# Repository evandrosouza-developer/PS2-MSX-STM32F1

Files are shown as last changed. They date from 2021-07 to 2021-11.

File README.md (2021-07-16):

# STM32: PS/2 to USB Converter

This code facilitates a STM32 chip to convert between PS/2 and MSX computer. It is meant to connect a keyboard, which only provides a PS/2 connector, to a MSX (or any one that have a up to 15 active columns and reads zeroes througth 8 bits - up to 15 x 8 matrix) computer.
This code powers and has been tested on the following Windows keyboards with brazilian 275 layout:
- Compaq RT235BTWBR;
- Clone KE11090749;
- Clone #09100.

The original code was originally developed based on:
- Cherry G80-3000LSMDE;

## Dependencies

- `arm-none-eabi-gcc`
- `arm-none-eabi-gdb`
- `arm-none-eabi-binutils`
- `arm-none-eabi-newlib`
- `stlink`
- `openocd (if you wnat to debug)`
- `mpfr`

## Preparations

After cloning the repository you need to make the following preparations:

```
git submodule init
git submodule update
cd libopencm3
make
cd ..
make
```

## Hardware and Setup

You will obviously need a STM32F103C8T6 chip. I have used a chinese blue pill. The software was made thinking in use of compatible processors, like GD32 for example. The software was made considering 8.000Mhz oscillator crystal, to clock the STM32F103C8T6 microcontroller chip at 72MHz. The connections are:

1) PS/2 Keyboard:
- Clock Pin PA12 - Connect to PS/2 mini-din 45322 pin 5 throught R16;
- Data Pin PA9 - Connect to PS/2 mini-din pin 1 throught R18;
- +5V PS/2 power - Connect collector of Q2 to mini-din pin 4;
- GND - Connect GNDD (Digital Ground) to mini-din pin 3.

2) MSX computer:
Obs.: You have to access PPI Ports B0 to B7 (Lines X0 to X7), Port C0 to C3 (Y0 to Y3), Port C6 (Caps Lock, pin 11 of DIP package), and for Russian and Japanese Computers (Cyrillic and Kana alphabets), you have to get access to YM2149 IOB7, pin 6 of DIP package.
- Y3 - Connect to MSX PPI 8255 Signal PC3;
- Y2 - Connect to MSX PPI 8255 Signal PC2;
- Y1 - Connect to MSX PPI 8255 Signal PC1;
- Y0 - Connect to MSX PPI 8255 Signal PC0;
- X7 - Connect to MSX PPI 8255 Signal PB7 (Hotbit HB-8000 CI-15 Pin 25);
- X6 - Connect to MSX PPI 8255 Signal PB6 (Hotbit HB-8000 CI-15 Pin 24);
- X5 - Connect to MSX PPI 8255 Signal PB5 (Hotbit HB-8000 CI-15 Pin 23);
- X4 - Connect to MSX PPI 8255 Signal PB4 (Hotbit HB-8000 CI-15 Pin 22);
- X3 - Connect to MSX PPI 8255 Signal PB3 (Hotbit HB-8000 CI-15 Pin 21);
- X2 - Connect to MSX PPI 8255 Signal PB2 (Hotbit HB-8000 CI-15 Pin 20);
- X1 - Connect to MSX PPI 8255 Signal PB1 (Hotbit HB-8000 CI-15 Pin 19);
- X0 - Connect to MSX PPI 8255 Signal PB0 (Hotbit HB-8000 CI-15 Pin 18);
- Caps LED - Connect to MSX PPI 8255 Signal PC6 (Hotbit HB-8000 CI-15 Pin 11 / Expert XP-800 CI-4);
- Kana LED - Connect to MSX YM2149 IOB7, pin 6 of DIP package. If the MSX doesn't have this, you can leave it open, as it already has an internal pull-up connection.

3) Serial connection: Needed only to update internal PS/2 to MSX key mapping Database. To create this Intel Hex file, better to use the Macro based Excel file, so you have to trust and enable macro excecution in excel app.
The structure of the Database is:
	The  three first columns of each line are the mapped scan codes;
	The 4th column is The Control Byte, detailed bellow:
	CONTROL BYTE:
		High nibble is Reserved;
		(bit 3) Combined Shift;
		(bit 2) Reserved-Not used;
		(bits 1-0) Modifyer Type:
		.0 - Default mapping
		.1 - NumLock Status+Shift changes
		.2 - PS/2 Shift
		.3 - Reserved-Not used
	
	This table has 3 modifyers: Up two MSX keys are considered to each mapping behavior modifying:
	
	5th and 6th columns have the mapping ".0 - Default mapping";
	7th e 8th columns have the mapping ".1 - NumLock Status+Shift changes";
	9th and 10th columns have the mapping ".2 - PS/2 Shift", where I need to
	release the sinalized Shift in PS/2 to the MSX and put the coded key, and so,
	release them, reapplying the Shift key, deppending on the initial state;

	Each column has a MSX coded key, with the sollwing structure:
	(Bit 7:4) MSX Y PPI 8255 PC3:0 is send to an OC outputs BCD decoder, for example:
					 In the case of Hotbit HB8000, the keyboard scan is done as a 9 columns scan, CI-16 7445N 08 to 00;
					 If equals to 1111 (Y=15), there is no MSX key mapped.
	(Bit 3)	 		 0: keypress
					 1: key release;
	(Bit 2:0) MSX X, ie, which bit will carry the key, to be read by PPI 8255 PB7:0.

Use a ST-Link v2 Programmer (or similar) to flash the program using `make flash` onto the STM32.

# PS2-MSX-STM32F1
# PS2-MSX-STM32F1

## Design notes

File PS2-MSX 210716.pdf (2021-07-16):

PPT模板下载：www.1ppt.com/moban/ 行业PPT模板：www.1ppt.com/hangye/ 节日PPT模板：www.1ppt.com/jieri/ PPT素材下载：www.1ppt.com/sucai/ PPT背景图片：www.1ppt.com/beijing/ PPT图表下载：www.1ppt.com/tubiao/
优秀PPT下载：www.1ppt.com/xiazai/ | PPT教程： www.1ppt.com/powerpoint/
Word教程： www.1ppt.com/word/ | Excel教程：www.1ppt.com/excel/
资料下载：www.1ppt.com/ziliao/
PPT课件下载：www.1ppt.com/kejian/
范文下载：www.1ppt.com/fanwen/

# PS/2 Keyboard for MSX And Legacy computers

## Evandro Souza <evandro.r.souza@gmail.com

# Based on ARM Cortex M3 Blue Pill STM32F103C8T6

# Introdução

O principal objetivo foi aprender a usar o Ecossistema de Desenvolvimento aberto (free) ARM Core M3

Para tal, escolhi uma aplicação de missão crítica, implementando facilidades de configuração normalmente não observadas nas várias soluções inteligentes já implementadas, como, por exemplo, permitir a atualização da tabela de conversão sem a necessidade e de recompilar o código.

Solução simples e de baixo custo

# Índice

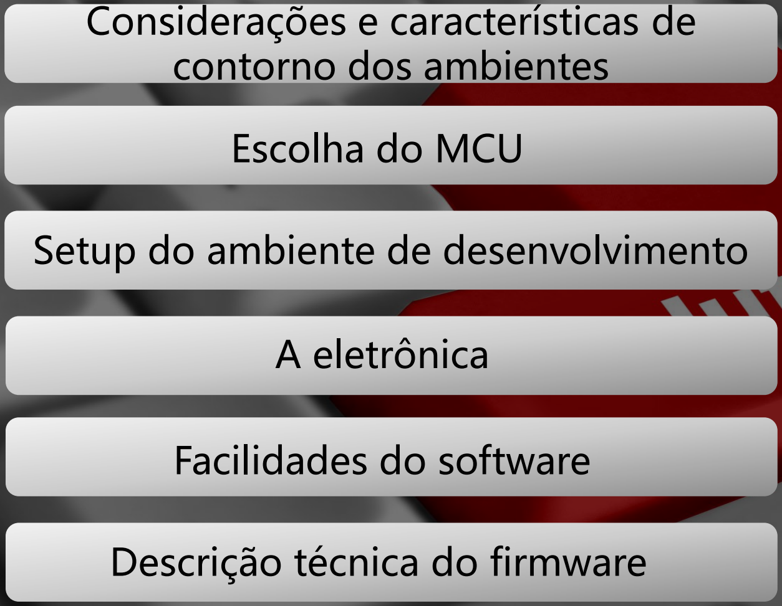
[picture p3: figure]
Considerações e características de contorno dos ambientes; Escolha do MCU; Setup do ambiente de desenvolvimento; A eletrônica; Facilidades do software; Descrição técnica do firmware

# Assunto do momento

# Considerações e características de

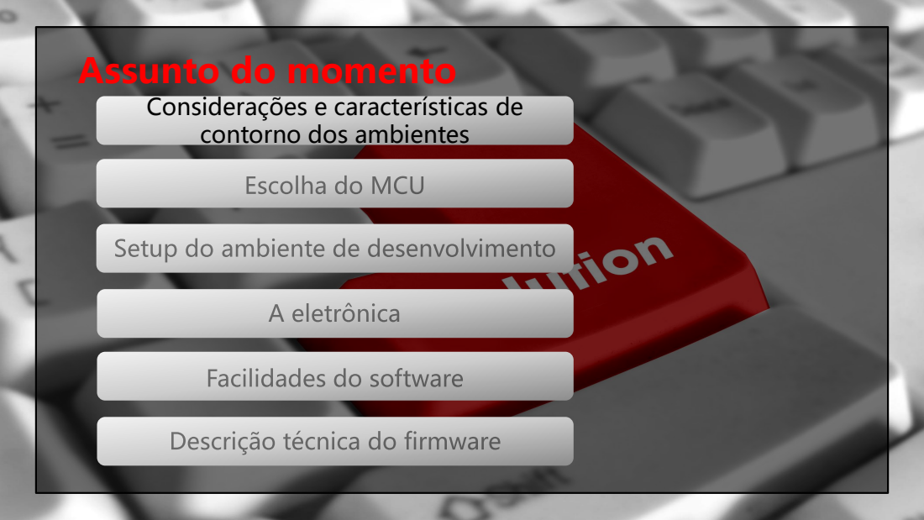
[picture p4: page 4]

contorno dos ambientes

# Esquemas exemplo de MSX

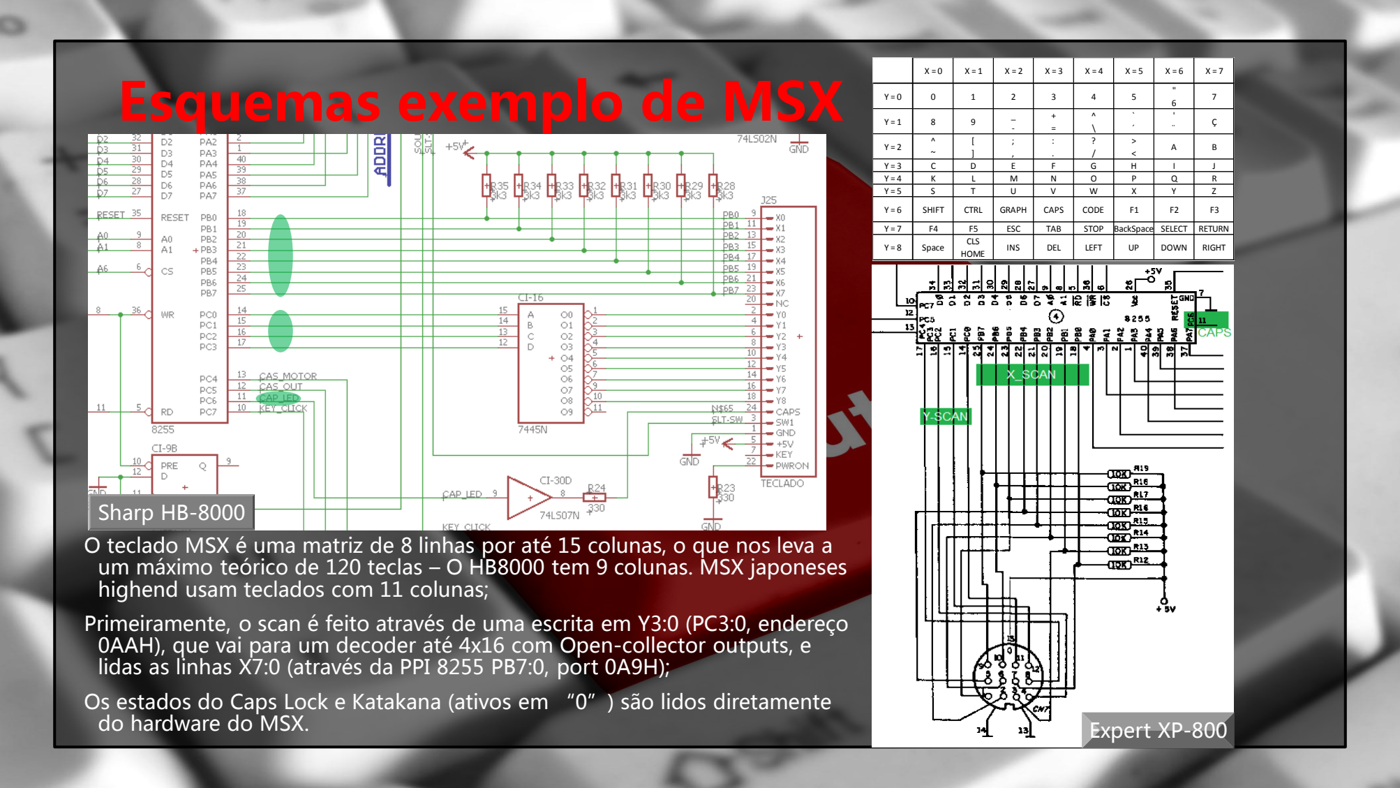
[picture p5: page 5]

O teclado MSX é uma matriz de 8 linhas por até 15 colunas, o que nos leva a um máximo teórico de 120 teclas – O HB8000 tem 9 colunas. MSX japoneses highend usam teclados com 11 colunas;
Primeiramente, o scan é feito através de uma escrita em Y3:0 (PC3:0, endereço 0AAH), que vai para um decoder até 4x16 com Open-collector outputs, e lidas as linhas X7:0 (através da PPI 8255 PB7:0, port 0A9H);
Os estados do Caps Lock e Katakana (ativos em “0”) são lidos diretamente do hardware do MSX.

Sharp HB-8000

Expert XP-800

| X = 0 | X = 1 | X = 2 | X = 3 | X = 4 | X = 5 | X = 6 | X = 7
Y = 0 | 0 | 1 | 2 | 3 | 4 | 5 | " 6 | 7
Y = 1 | 8 | 9 | _ - | + = | ^ \ | ` ´ | ' ¨ | Ç
Y = 2 | ^ ~ | [ ] | ; , | : . | ? / | > < | A | B
Y = 3 | C | D | E | F | G | H | I | J
Y = 4 | K | L | M | N | O | P | Q | R
Y = 5 | S | T | U | V | W | X | Y | Z
Y = 6 | SHIFT | CTRL | GRAPH | CAPS | CODE | F1 | F2 | F3
Y = 7 | F4 | F5 | ESC | TAB | STOP | BackSpace | SELECT | RETURN
Y = 8 | Space | CLS HOME | INS | DEL | LEFT | UP | DOWN | RIGHT

# Temporização

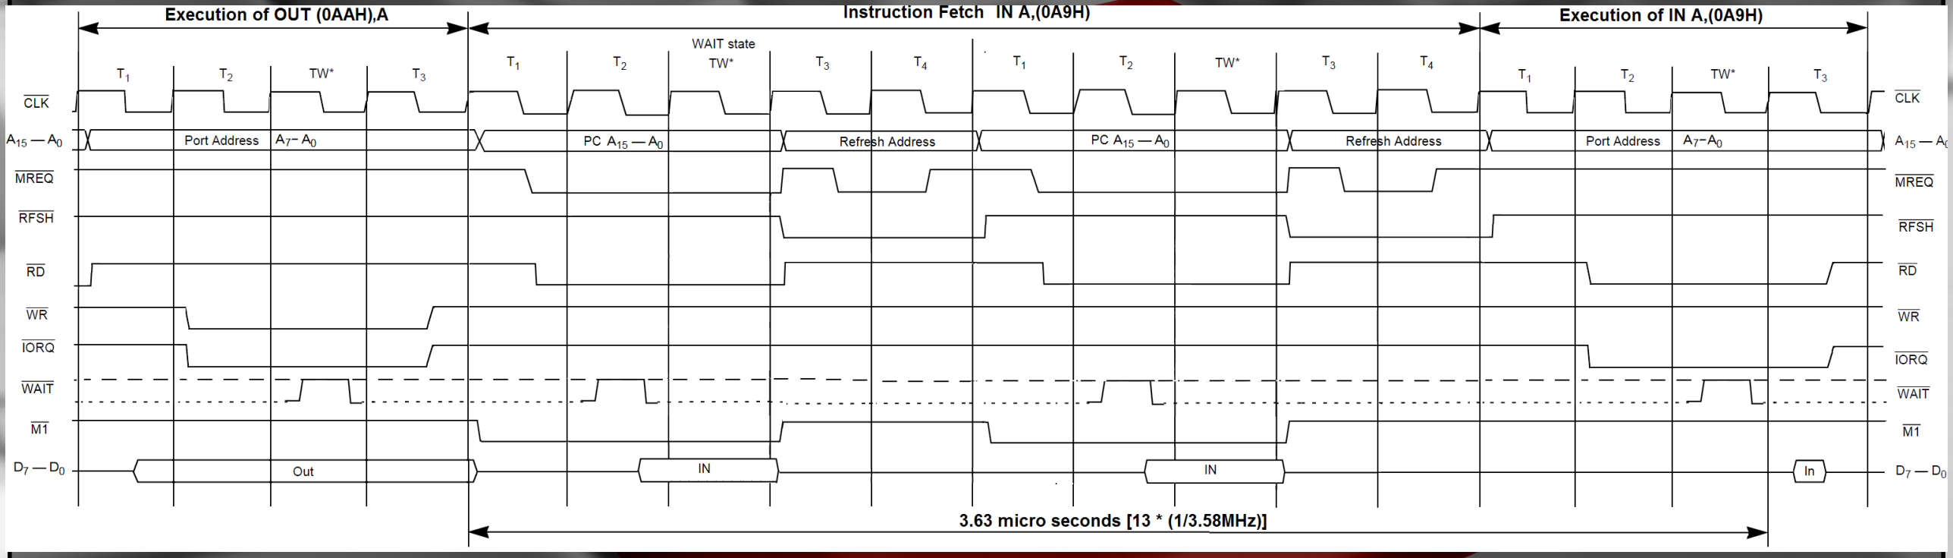
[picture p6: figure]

Mapeamento detalhado da temporização de leitura de teclado MSX (OUT seguido de IN)
- O tempo após a atualização do Y (OUT (0AAH), A) disponível para responder com a linha (X7:0) é de 3,6µs;
- A leitura de teclado (IN A, 0A9H) não é feita somente após o OUT (exemplo: jogos), portanto, o adaptador deve estar preparado para atualizar X, para o respectivo Y que estiver registrado no momento, de acordo com as atualizações do teclado PS/2.

# O Teclado PS/2 - Temporização

- O teclado PS/2 se comunica através de uma comunicação serial síncrona half duplex de dois fios: Dados e Clock;
- A velocidade do clock varia entre 10K e 16,7KHz;
Seguem diagramas de tempo detalhado para:
1) Comunicação Teclado para o host (PC ou adaptador):

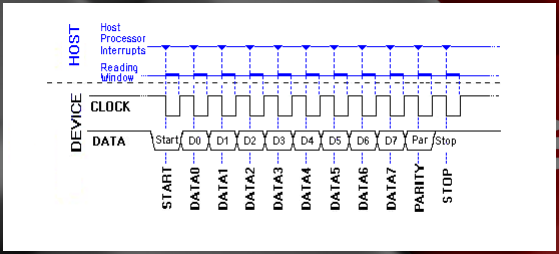
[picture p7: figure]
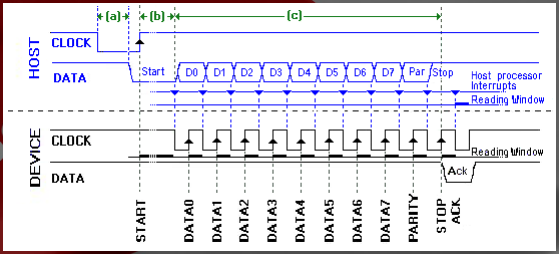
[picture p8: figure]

- (a) Host força o clock nível baixo (0) por pelo menos 100µs;
- (b) É o tempo que o teclado requer para enviar clocks para receber o frame, e pode levar até 15ms;
- (c) É o tempo para concluir a recepção do frame, após o teclado iniciar o envio do clock, e deve ser até 2ms;
2) Envio de comandos do Host para o teclado

# O Teclado PS/2 - Layout

- Há várias teclas exclusivas de MSX, como Graph, Code, Select e Stop. Tal raciocínio vale também para o teclado PS/2;
- Os scan codes não têm relação com as funções indicadas nos keytops;
- Os scan codes têm tamanhos que variam de 1 a 8 bytes;
- O teclado PS/2 envia códigos de scan tipo 2 para o host e auto-repeat da última tecla pressionada;
- Os códigos de scan são dependentes do layout físico – Por exemplo: Os códigos 51 (tecla / ao lado do Shift direito) e 6D (tecla . do teclado numérico reduzido) são exclusivos do teclado ABNT2 (Id=275);
- Segue exemplo do teclado base para este desenvolvimento (Teclado ABNT2) com os scan codes de make (pressionar):

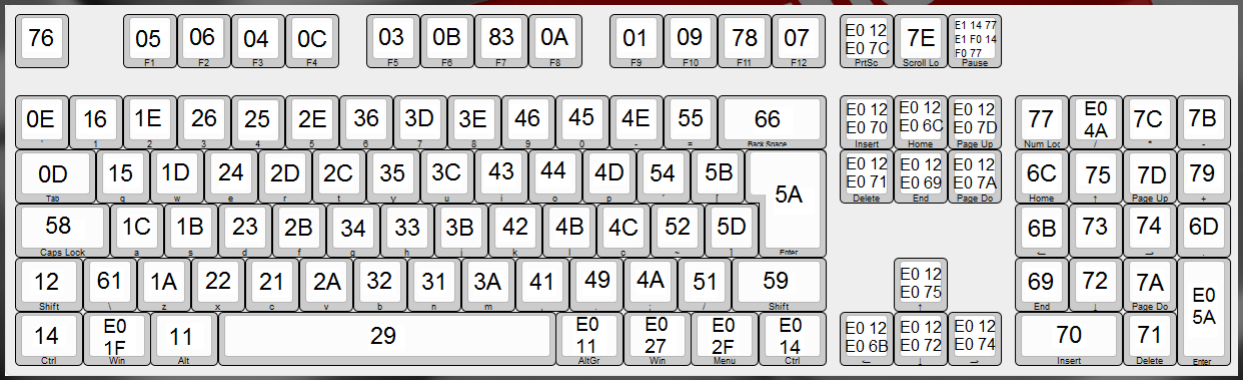
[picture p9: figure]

# Assunto do momento

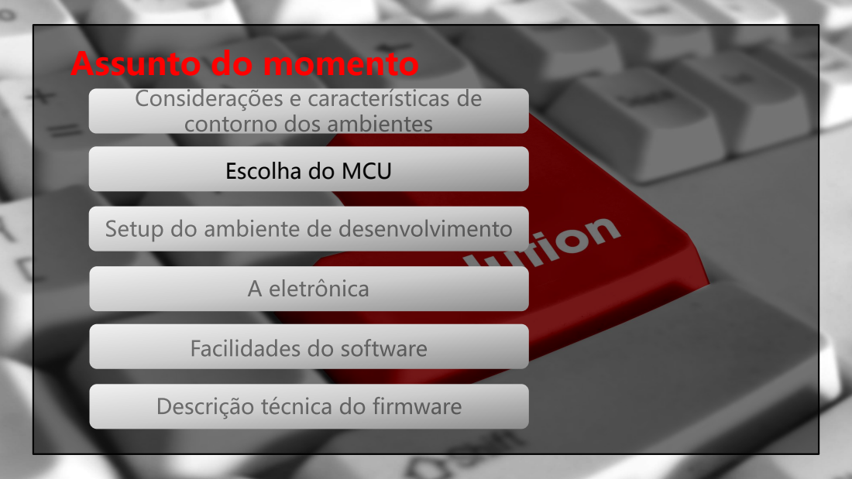
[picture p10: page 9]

Escolha do MCU

# Escolha do MCU (MicroController Unit)

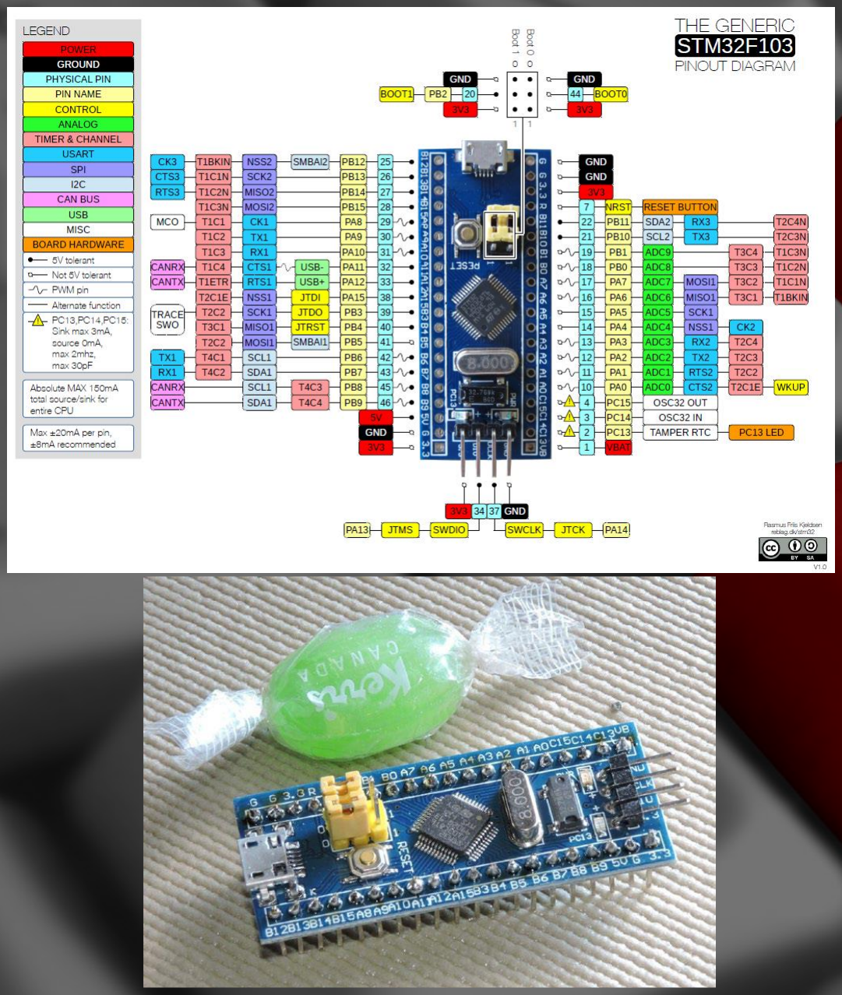
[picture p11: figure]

Características atendidas

1. Baixo consumo de energia;
2. 16 Portas capazes de suportar 5V;
3. Portas de saída devem ser programáveis como OD (Open Drain);
4. Portas OD devem poder ter seu estado real lido a qualquer tempo;
5. Pelo menos 7 pinos para interrupção externa;
6. Os pinos de interrupção externa conectados ao Y_SCAN não devem compartilhar recursos de interrupção;
7. Deve ter capacidade de reprogramar a flash através do firmware;
8. Documentação abundante;
9. Ecossistema de desenvolvimento gratuito;
10. Baixo custo;
11. Ser de fácil aquisição.

# Assunto do momento

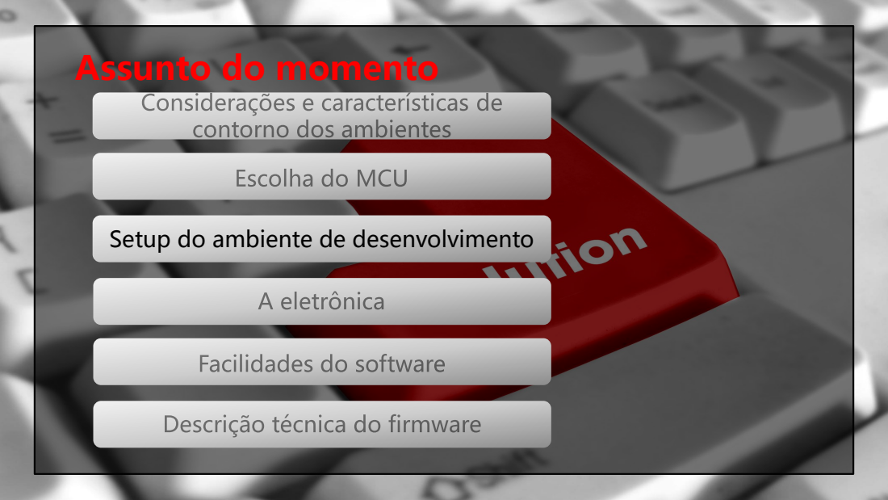
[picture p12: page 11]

Setup do ambiente de desenvolvimento

# Setup do ambiente de desenvolvimento

Linux Ubuntu 20.04 | ARM GCC Tools | LibOpenCM3 | OpenOCD

Os passos iniciais foram dados com a orientação do excelente livro:
Warren Gay, Beginning STM32 Developing with FreeRTOS, libopencm3 and GCC,
que | me | foi | apresentado | por | Ismael | Lopes | da | Silva, | site
https://www.embarcados.com.br/serie/programacao-com-a-placa-blue-pill/, | a
quem sou muito grato!

Visual Studio Code

# Assunto do momento

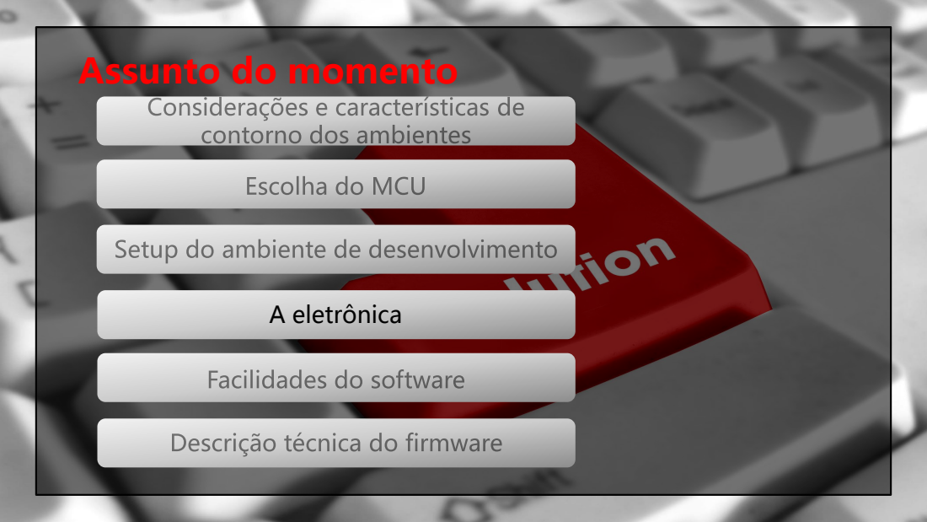
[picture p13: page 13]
A eletrônica

# A Eletrônica

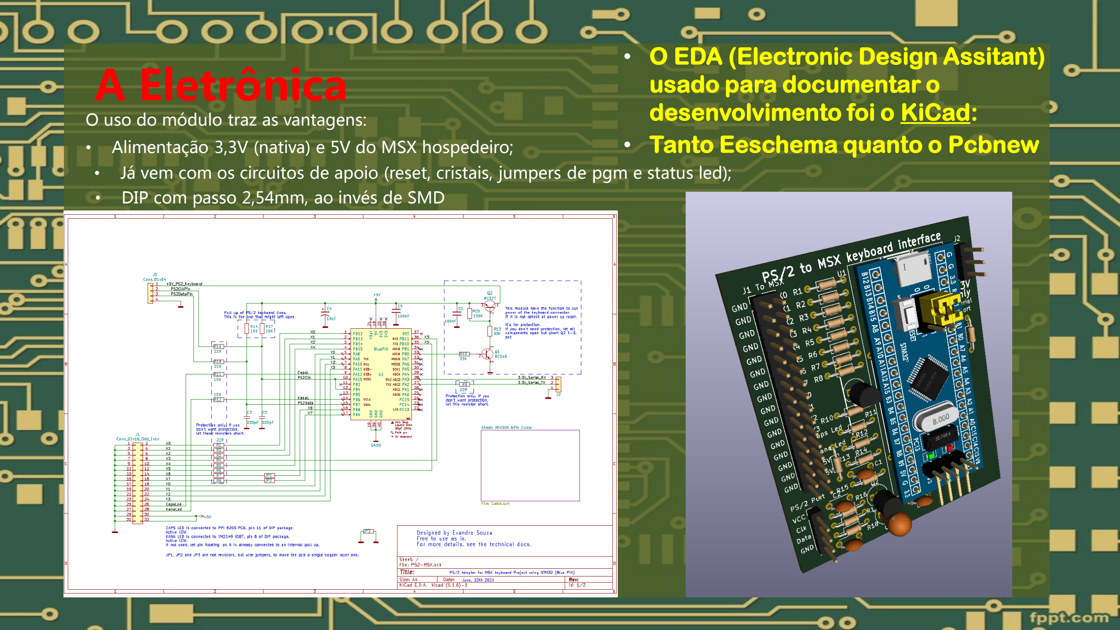
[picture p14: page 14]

O uso do módulo traz as vantagens:
- Alimentação 3,3V (nativa) e 5V do MSX hospedeiro;
- Já vem com os circuitos de apoio (reset, cristais, jumpers de pgm e status led);
- DIP com passo 2,54mm, ao invés de SMD

### - O EDA (Electronic Design Assitant) usado para documentar o desenvolvimento foi o KiCad: - Tanto Eeschema quanto o Pcbnew

# A eletrônica

100% da eletrônica externa ao módulo tem por função a proteção do teclado/módulo/MSX hospedeiro;
- Desenergizar o teclado quando o mesmo não for detectado no boot (start-up);
- C2 e C3 absorvem os picos de chaveamento, diminuindo desta forma, riscos de falsa detecção das informações do teclado PS/2.
- O consumo medido é de 23mA @ 5V;
- Dimensões da PCB de face simples: 65 x
55mm;
- Embora o STM32 seja capaz de atuar como um dispositivo USB, não sobraram recursos para implementação futura de comunicação via USB. Até a comunicação serial foi atendida através de portas de 3,3V (não tolerantes a 5V).

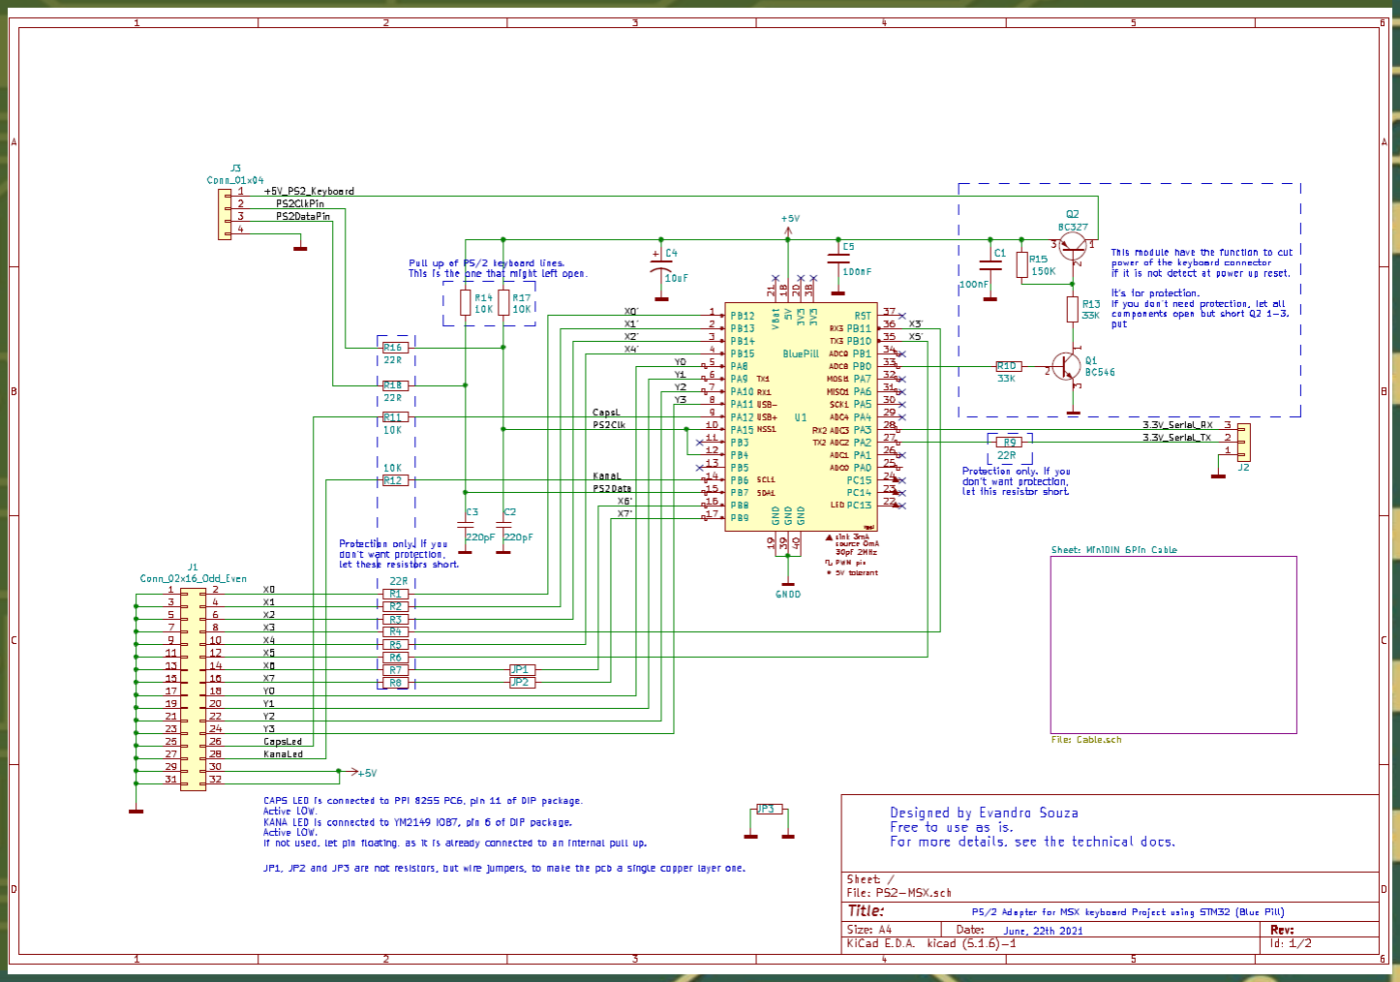
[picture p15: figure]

# Assunto do momento

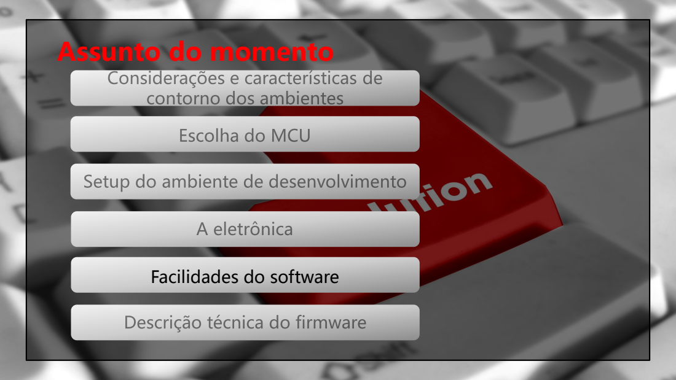
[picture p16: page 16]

Facilidades do software

# Facilidades do software

O mapeamento (Database) de ambos os teclados pode ser trocado a qualquer tempo: Basta colocar um terminal capaz de enviar arquivo texto com a configuração de serial 38400, 8 n, 1, ligar a este módulo sem o teclado PS/2 e seguir as instruções: Uma operação de 15 segundos.

O Database é alterado via um arquivo Intel Hex, montado pelo arquivo excel, que será enviado por um programa terminal (exemplo: Putty).

A interface controla o NumLock, da mesma forma que um PC, e os Leds de CapsLock e Scroll Lock são coletados do hardware do MSX hospedeiro, sendo que o Scroll Lock é mapeado para Katakana (ou Cirílico ou Korean).

O MSX informa a coluna (Y_Scan) e a interface responde com a linha solicitada. Se não há alterações no Y_Scan, a interface atualizará (somente) a linha apontada pelo Y_Scan, conforme os eventos do teclado PS/2 mapeados no Database.

Os eventos válidos do teclado PS/2 para esta interface são o pressionar teclas e o liberar das mesmas. Auto repeat não têm sentido para esta aplicação, por isso, é enviado ao teclado um comando para deixar o autorepeat para 2CPS e o autorepeat delay em 1,0s.

# Assunto do momento

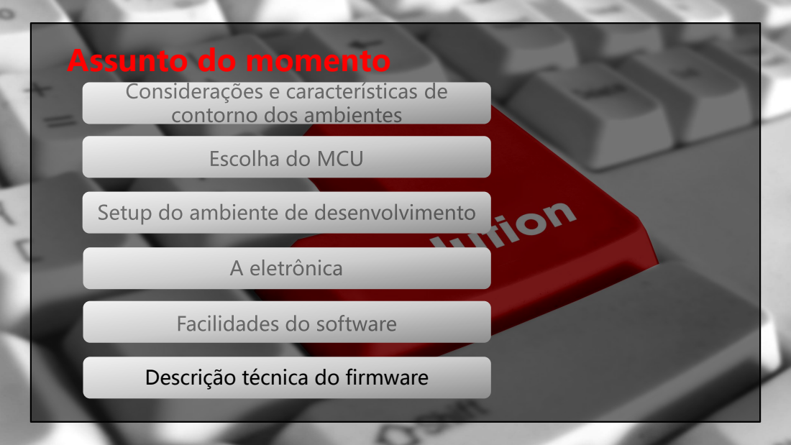
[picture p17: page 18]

Descrição técnica do firmware

# Descrição Técnica do Firmware

A técnica implementada foi a programação em Bare metal, ou seja, não foi implementado

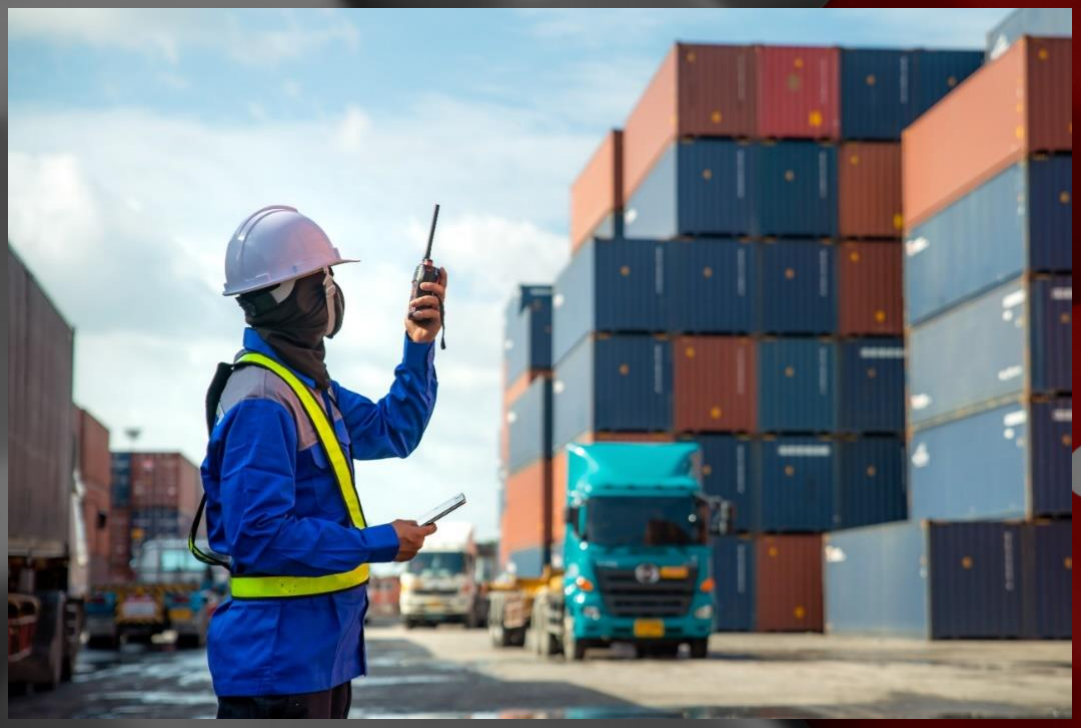
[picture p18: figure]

sobre RTOS;

A linguagem adotada foi o C++, com alguns módulos em C

A alocação das tarefas (função do Despachante) foi baseada em interrupções:
- Hardware: MSX Y-Scan & PS/2 keyboard;
- Software: System timer, com taxa de 30Hz & Timer2, com resolução de µs.

* O código fonte pode ser acessado através da minha página do github: https://github.com/evandrosouza-developer/PS2-MSX-STM32F1

# Descrição Técnica do Firmware

Arquivos:
- ps2-msx.cpp
- Contém o main.
Gerencia o constructor (setup) de cada módulo. O loop principal apenas atualiza os Leds do teclado PS/2.
Interface
- msxmap.cpp
- msxmap.h
Grupo de controle do mapeamento e adapatação dos teclados PS/2 e MSX. Contém as rotinas de pré-montagem do dado enviado ao MSX na interrupção ou na ausência desta. É onde fica o Database default.

Interface

- ps2handl.cpp
- ps2handl.h
Trata bit a bit a comunicação, Recebe e envia dados do teclado por byte e envia evento multibyte (o Scan Code)

Interface

- flash_intelhex.c
- flash_intelhex.h
Lê o arquivo Database no formato Intel Hex pela serial e atualiza a flash interna do STM32

Interface

- port-def.h
Definições de uso de Portas Extremamente conectado ao
hardware

Interface

- sys_timer.cpp
- sys_timer.h
Clock ARM, usado em 30Hz. É onde são lidos

os estados de Caps e Kana. Marca a cadência do LED de status e despacha para msxmap os Scan Codes preparados

Interface

- serial.c
- serial.h
Implementa todas as entradas e saídas com administração de buffer e Xon/Xoff protocol
Interface | Interface
- hr_timer.cpp
- hr_timer.h
Tem as funções de dar os delays de µs e, na função Capture, informar a interrupção do clock PS/2

Cada .cpp ou .c contém as rotinas de setup,

rotinas de trabalho e suas respectivas

Interrupt Service Routines.

Os .h são usados para definições e divulgar

as rotinas públicas, além da adaptação de

header para CPP.

# THANKS

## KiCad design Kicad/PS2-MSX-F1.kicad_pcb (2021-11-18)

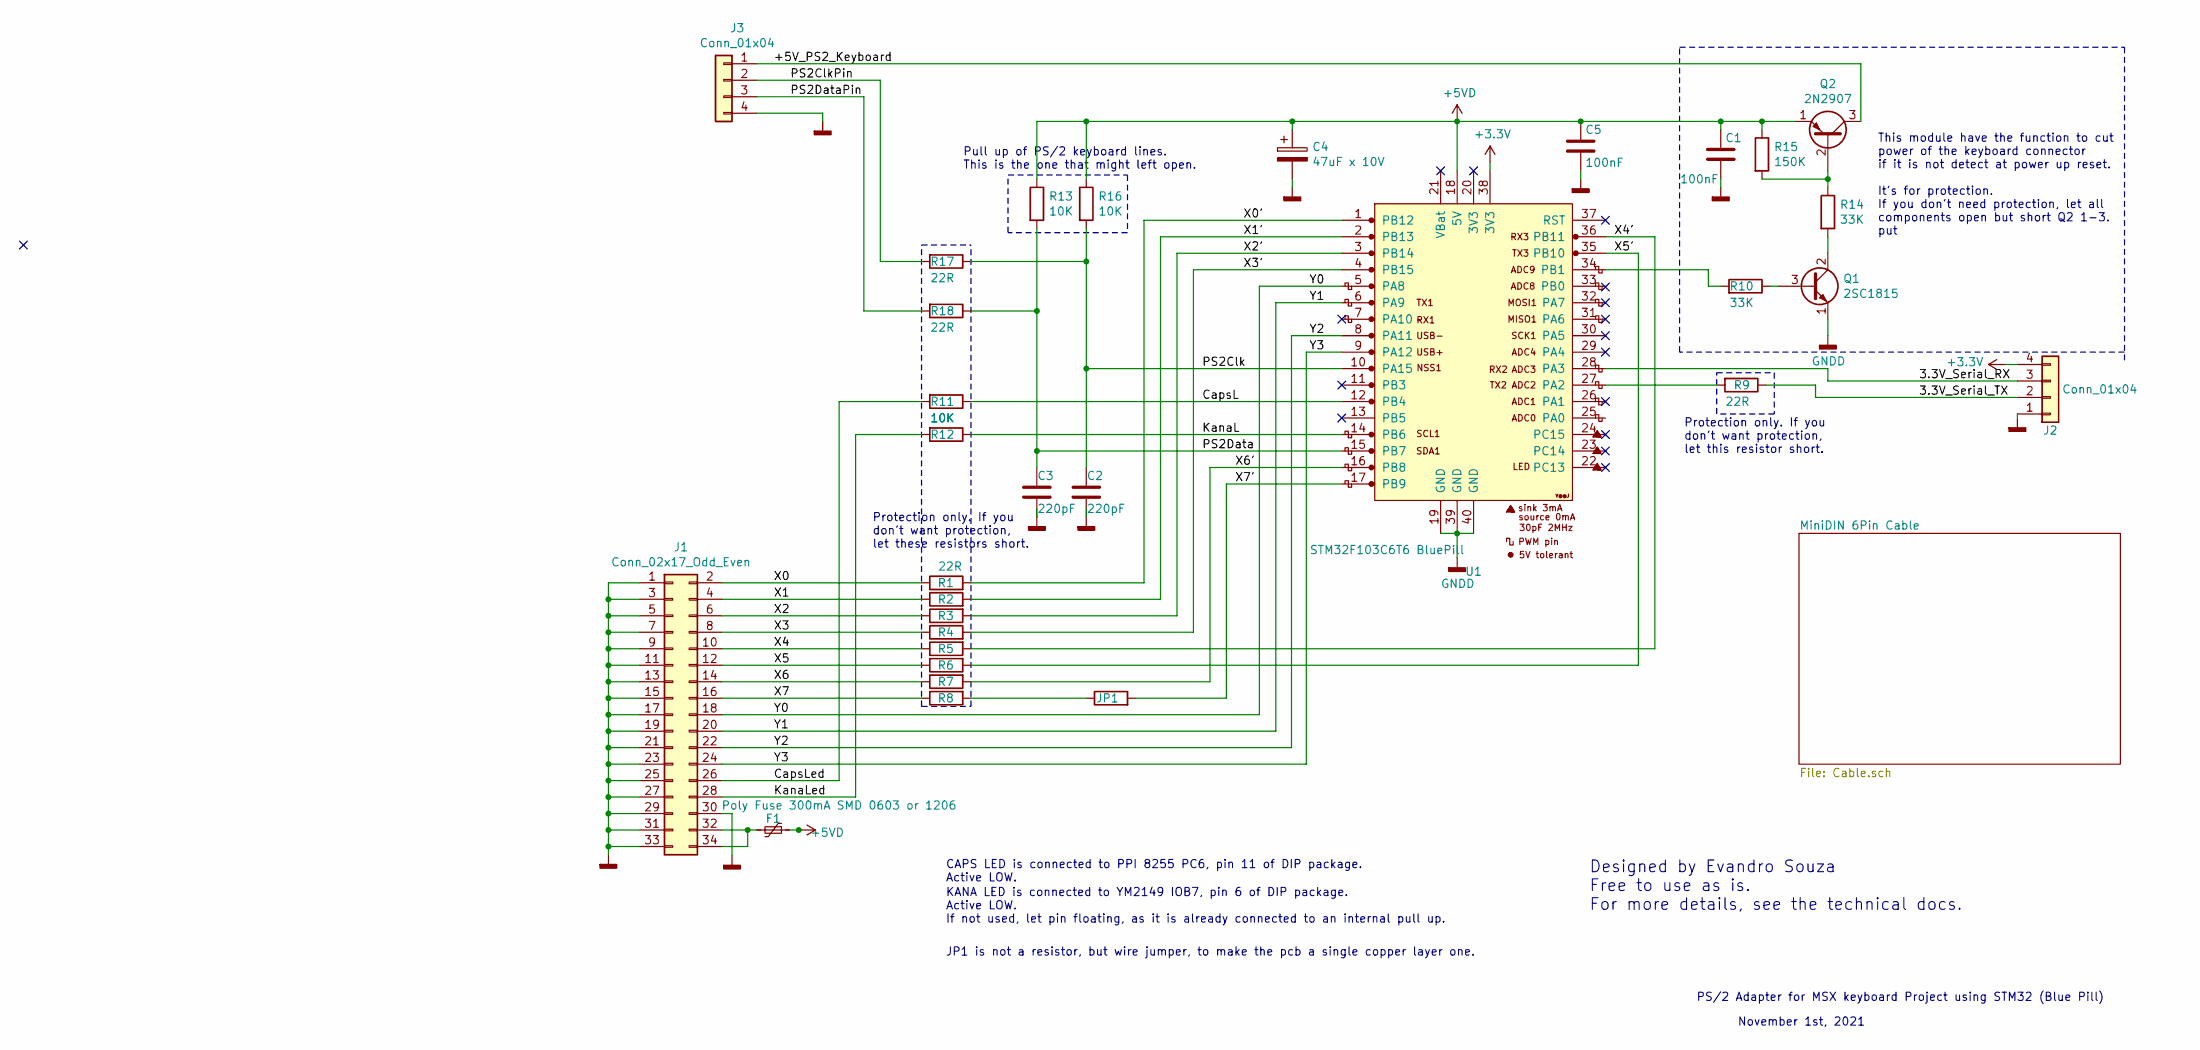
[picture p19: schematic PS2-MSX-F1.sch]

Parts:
C1, C5: 100nF; C_Disc_D4.3mm_W1.9mm_P5.00mm
C2, C3: 220pF; C_Disc_D4.3mm_W1.9mm_P5.00mm
C4: 47uF x 10V; CP_Radial_D5.0mm_P2.50mm
F1: Poly Fuse 300mA SMD 0603 or 1206; Fuse_1206_0603_3216Metric_Pad1.42x1.75mm_HandSolder
J1: Conn_02x17_Odd_Even; PinHeader_2x17_P2.54mm_Vertical
J2: Conn_01x04; PinSocket_1x04_P2.54mm_Vertical
J3: Conn_01x04; PinHeader_1x04_P2.54mm_Vertical
JP1: .01; SolderWire-0.25sqmm_1x01_D0.65mm_OD1.7mm_Relief.kicad_SM2000
Q1: 2SC1815; TO-92_Inline
Q2: 2N2907; TO-92_Inline
R1, R2, R3, R4, R5, R6, R7, R8, R9, R17, R18: 22R; R_Axial_DIN0204_L3.6mm_D1.6mm_P7.62mm_Horizontal
R10, R14: 33K; R_Axial_DIN0204_L3.6mm_D1.6mm_P7.62mm_Horizontal
R11, R12, R13, R16: 10K; R_Axial_DIN0204_L3.6mm_D1.6mm_P7.62mm_Horizontal
R15: 150K; R_Axial_DIN0204_L3.6mm_D1.6mm_P7.62mm_Horizontal
U1: STM32F103C6T6 BluePill; BluePill_1

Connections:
+3V3: J2.4, U1.38 (3V3)
+5VD: C1.1, C4.1, C5.1, F1.1, Q2.1 (E), R13.1, R15.1, R16.1, U1.18 (5V)
/3.3V_Serial_RX: J2.3, U1.28 (PA3)
/3.3V_Serial_TX: J2.2, R9.1
/+5V_PS2_Keyboard: J3.1, Q2.3 (C)
/CapsL: R11.1, U1.12 (PB4)
/CapsLed: J1.26, R11.2
/KanaL: R12.1, U1.14 (PB6)
/KanaLed: J1.28, R12.2
/PS2Clk: C2.1, R16.2, R17.1, U1.10 (PA15)
/PS2ClkPin: J3.2, R17.2
/PS2Data: C3.1, R13.2, R18.1, U1.15 (PB7)
/PS2DataPin: J3.3, R18.2
/X0: J1.2, R1.1
/X0': R1.2, U1.1 (PB12)
/X1: J1.4, R2.1
/X1': R2.2, U1.2 (PB13)
/X2: J1.6, R3.1
/X2': R3.2, U1.3 (PB14)
/X3: J1.8, R4.1
/X3': R4.2, U1.4 (PB15)
/X4: J1.10, R5.1
/X4': R5.2, U1.36 (PB11)
/X5: J1.12, R6.1
/X5': R6.2, U1.35 (PB10)
/X6: J1.14, R7.1
/X6': R7.2, U1.16 (PB8)
/X7: J1.16, R8.1
/X7': JP1.2, U1.17 (PB9)
/Y0: J1.18, U1.5 (PA8)
/Y1: J1.20, U1.6 (PA9)
/Y2: J1.22, U1.8 (PA11)
/Y3: J1.24, U1.9 (PA12)
GNDD: C1.2, C2.2, C3.2, C4.2, C5.2, J1.1, J1.3, J1.5, J1.7, J1.9, J1.11, J1.13, J1.15, J1.17, J1.19, J1.21, J1.23, J1.25, J1.27, J1.29, J1.30, J1.31, J1.33, J2.1, J3.4, Q1.1 (E), U1.19 (GND), U1.39 (GND), U1.40 (GND)
unnamed: F1.2, J1.32, J1.34
unnamed: JP1.1, R8.2
unnamed: Q1.2 (C), R14.2
unnamed: Q1.3 (B), R10.1
unnamed: Q2.2 (B), R14.1, R15.2
unnamed: R9.2, U1.27 (PA2)
unnamed: R10.2, U1.34 (PB1)

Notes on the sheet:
KANA LED is connected to YM2149 IOB7, pin 6 of DIP package. Active LOW. If not used, let pin floating, as it is already connected to an internal pull up.
CAPS LED is connected to PPI 8255 PC6, pin 11 of DIP package. Active LOW.
November 1st, 2021
PS/2 Adapter for MSX keyboard Project using STM32 (Blue Pill)
This module have the function to cut power of the keyboard connector if it is not detect at power up reset. It's for protection. If you don't need protection, let all components open but short Q2 1-3. put
Designed by Evandro Souza Free to use as is. For more details, see the technical docs.
JP1 is not a resistor, but wire jumper, to make the pcb a single copper layer one.
Protection only. If you don't want protection, let these resistors short.
Protection only. If you don't want protection, let this resistor short.
Pull up of PS/2 keyboard lines. This is the one that might left open.

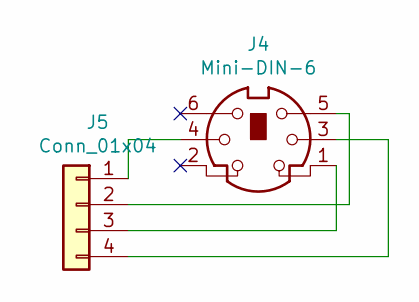
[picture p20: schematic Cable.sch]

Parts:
J4: Mini-DIN-6
J5: Conn_01x04

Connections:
unnamed: J4.1, J5.3
unnamed: J4.3, J5.4
unnamed: J4.4, J5.1
unnamed: J4.5, J5.2

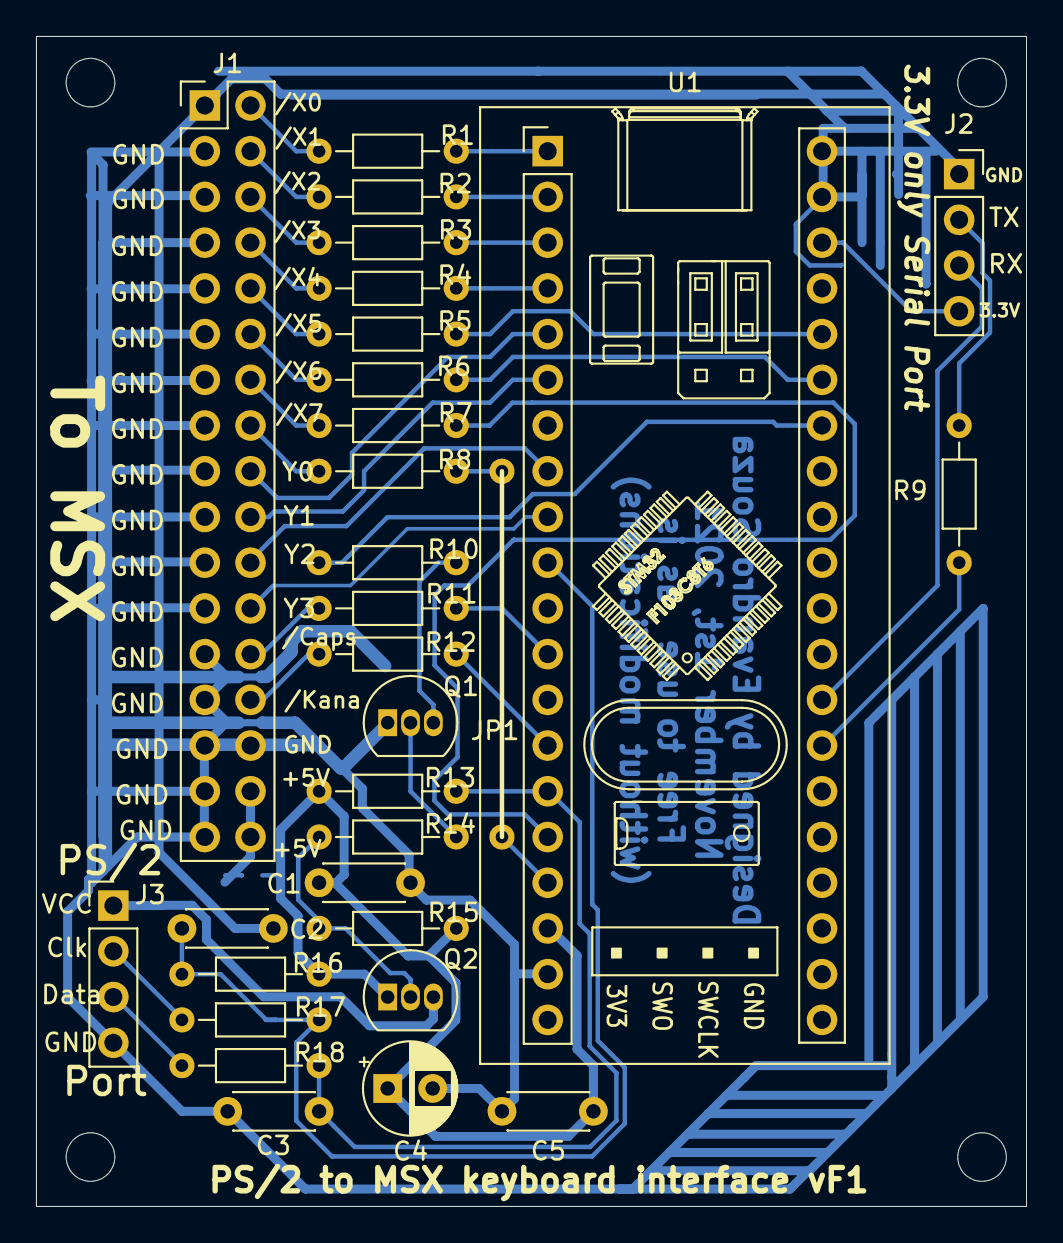
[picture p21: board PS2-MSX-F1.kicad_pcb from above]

Board: 2 copper layers, 55.0 x 65.0 mm, 31 parts (1 on the bottom side), 41 nets.

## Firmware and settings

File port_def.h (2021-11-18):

#pragma once

//Use Tab width=2

#ifdef __cplusplus
extern "C" {
#endif

#define X7_port							GPIOB
#define X7_pin_id						GPIO9
#define X6_port							GPIOB
#define X6_pin_id						GPIO8
#define X5_port							GPIOB
#define X5_pin_id						GPIO10
#define X4_port							GPIOB
#define X4_pin_id						GPIO15
#define X3_port							GPIOB
#define X3_pin_id						GPIO11
#define X2_port							GPIOB
#define X2_pin_id						GPIO14
#define X1_port							GPIOB
#define X1_pin_id						GPIO13
#define X0_port							GPIOB
#define X0_pin_id						GPIO12
#define Y3_port							GPIOA
#define Y3_pin_id						GPIO12		//port A10 (Y2) broken
#define Y3_exti							EXTI12
#define Y2_port							GPIOA		//port A10 (Y2) broken
//#define Y2_pin_id						GPIO10		//port A10 (Y2) broken
#define Y2_pin_id						GPIO11		//port A10 (Y2) broken
#define Y2_exti							EXTI4
#define Y1_port							GPIOA
#define Y1_pin_id						GPIO9
#define Y1_exti							EXTI9
#define Y0_port							GPIOA
#define Y0_pin_id						GPIO8
#define Y0_exti							EXTI8
#define CAPSLOCK_port				GPIOA
#define CAPSLOCK_pin_id			GPIO12
#define CAPSLOCK_exti				EXTI12
#define KANA_port						GPIOB
#define KANA_pin_id					GPIO6
#define KANA_exti						EXTI6
//SERIAL2_port							GPIOA (Pre-defined)
//SERIAL2_TX_pin_id					GPIO2 (Pre-defined)
//SERIAL2_RX_pin_id					GPIO3 (Pre-defined)


#define ps2_data_pin_port		GPIOB
#define ps2_data_pin_id			GPIO7
#define ps2_clock_pin_port	GPIOA
#define ps2_clock_pin_id		GPIO15
#define ps2_power_ctr_port	GPIOB	
#define ps2_power_ctr_pin		GPIO1	


//Para debug
#define SYSTICK_port				GPIOA
#define SYSTICK_pin_id			GPIO0
#define TIM2CC1_pin_id			GPIO1
#define BIT0_pin_port				GPIOA
#define BIT0_pin_id					GPIO4
#define INT_TIM2_port				GPIOA
#define TIM2UIF_pin_id			GPIO5
#define Dbg_Yint_port				GPIOA
#define Dbg_Yint0e1_pin_id	GPIO6
#define Dbg_Yint2e3_pin_id	GPIO7

#ifdef __cplusplus
}
#endif

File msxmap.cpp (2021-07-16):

#include <libopencm3/cm3/nvic.h>
#include <libopencm3/cm3/systick.h>
#include <libopencm3/stm32/rcc.h>
#include <libopencm3/stm32/gpio.h>
#include <libopencm3/stm32/exti.h>

#include "ps2handl.h"
#include "msxmap.h"
#include "port_def.h"
#include "serial.h"

//Use Tab width=2

//Variáveis globais: Visíveis por todo o contexto do programa
extern uint32_t systicks;											//Declared on sys_timer.cpp
volatile bool ps2numlockstate;
volatile bool update_ps2_leds;
volatile uint16_t msx_Y_scan;
//Place to store previous time for each Y last scan
volatile uint32_t previous_y_systick[ 16 ] = {0, 0, 0, 0, 0, 0, 0, 0, 0, 0, 0, 0, 0, 0, 0, 0 };

//Variable used to store the values of the X for each Y scan - Each Y has its own image of BSSR register
volatile uint32_t x_bits[ 16 ] = 
			{0x0000ff00, 0x0000ff00, 0x0000ff00, 0x0000ff00, 0x0000ff00, 0x0000ff00, 0x0000ff00, 0x0000ff00, 
			 0x0000ff00, 0x0000ff00, 0x0000ff00, 0x0000ff00, 0x0000ff00, 0x0000ff00, 0x0000ff00, 0x0000ff00};

uint8_t y_dummy;															//Read from MSX Database to sinalize "No keys mapping"
volatile uint8_t keycode[4];									//O 1º é a quantidade de bytes;
volatile uint8_t formerkeycode[4];						//O 1º é a quantidade de bytes;
bool compatible_database;

extern bool enable_xon_xoff;									//Declared on serial.c

#define MSX_DISP_QUEUE_SIZE							16
volatile static uint8_t msx_dispatch_keys_queue[MSX_DISP_QUEUE_SIZE];
volatile uint8_t msx_dispatch_kq_put;
volatile uint8_t msx_dispatch_kq_get;

#define MAX_LINHAS_VARRIDAS								306	//To acommodate maximum size of 3K (3072 lines of 10 bytes each)
#define MAX_TIME_OF_IDLE_KEYSCAN_SYSTICKS	5		//30 / 5 = 6 times per second is the maximum sweep speed
#define	Y_SHIFT														6		//Shift colunm

#define PRESS_RELEASE_BIT_POSITION				3
#define PRESS_RELEASE_BIT									1 << PRESS_RELEASE_BIT_POSITION //8

//The original SW was compiled to a Sharp/Epcom MSX HB-8000 and a brazilian PS/2 keyboard (ID=275)
//But it is possible to update the table sending a Intel Hex File through serial 2 (3.3V only):
//PA2 as TX and PA3 as RX, using the following communication parameters:
//Speed: 38400 bps
//8 bits
//No parity
//1 Stop bit
//no hardware flow control

#define SCB_BASE_ADDR				0xE000E008
#define SCB_AIRCR_OFFSET		0x0C

//Paste here the generated excel Conversion Database to make it with a default.
//Colar aqui Base de Dados de conversao gerada pelo excel para compilar com uma tabela default.
const uint8_t __attribute__((section("MSXDATABASE")))
	MSX_KEYB_DATABASE_CONVERSION[uint16_t (204)][uint8_t (10)] =
{
    {1, 0, 255, 255, 255, 255, 255, 255, 255, 255},
    {1, 0, 0, 244, 96, 112, 255, 255, 255, 255},
    {3, 0, 0, 244, 113, 255, 255, 255, 255, 255},
    {4, 0, 0, 244, 103, 255, 255, 255, 255, 255},
    {5, 0, 0, 244, 101, 255, 255, 255, 255, 255},
    {6, 0, 0, 244, 102, 255, 255, 255, 255, 255},
    {7, 0, 0, 244, 116, 255, 255, 255, 255, 255},
    {9, 0, 0, 244, 96, 113, 255, 255, 255, 255},
    {10, 0, 0, 244, 96, 103, 255, 255, 255, 255},
    {11, 0, 0, 244, 96, 101, 255, 255, 255, 255},
    {12, 0, 0, 244, 112, 255, 255, 255, 255, 255},
    {13, 0, 0, 244, 115, 255, 255, 255, 255, 255},
    {14, 0, 0, 244, 96, 22, 255, 255, 255, 255},
    {17, 0, 0, 244, 100, 255, 255, 255, 255, 255},
    {18, 0, 0, 244, 96, 255, 255, 255, 255, 255},
    {20, 0, 0, 244, 97, 255, 255, 255, 255, 255},
    {21, 0, 0, 244, 70, 255, 255, 255, 255, 255},
    {22, 0, 0, 244, 1, 255, 255, 255, 255, 255},
    {26, 0, 0, 244, 87, 255, 255, 255, 255, 255},
    {27, 0, 0, 244, 80, 255, 255, 255, 255, 255},
    {28, 0, 0, 244, 38, 255, 255, 255, 255, 255},
    {29, 0, 0, 244, 84, 255, 255, 255, 255, 255},
    {30, 0, 0, 244, 2, 255, 255, 255, 255, 255},
    {33, 0, 0, 244, 48, 255, 255, 255, 255, 255},
    {34, 0, 0, 244, 85, 255, 255, 255, 255, 255},
    {35, 0, 0, 244, 49, 255, 255, 255, 255, 255},
    {36, 0, 0, 244, 50, 255, 255, 255, 255, 255},
    {37, 0, 0, 244, 4, 255, 255, 255, 255, 255},
    {38, 0, 0, 244, 3, 255, 255, 255, 255, 255},
    {41, 0, 0, 244, 128, 255, 255, 255, 255, 255},
    {42, 0, 0, 244, 83, 255, 255, 255, 255, 255},
    {43, 0, 0, 244, 51, 255, 255, 255, 255, 255},
    {44, 0, 0, 244, 81, 255, 255, 255, 255, 255},
    {45, 0, 0, 244, 71, 255, 255, 255, 255, 255},
    {46, 0, 0, 244, 80, 255, 255, 255, 255, 255},
    {49, 0, 0, 244, 67, 255, 255, 255, 255, 255},
    {50, 0, 0, 244, 39, 255, 255, 255, 255, 255},
    {51, 0, 0, 244, 53, 255, 255, 255, 255, 255},
    {52, 0, 0, 244, 52, 255, 255, 255, 255, 255},
    {53, 0, 0, 244, 86, 255, 255, 255, 255, 255},
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
};


void msxmap::msx_interface_setup(void)
{
	//Not the STM32 default: Default MSX state - Release MSX keys;
	gpio_set(X7_port,
	X7_pin_id | X6_pin_id | X5_pin_id | X4_pin_id | X3_pin_id | X2_pin_id | X1_pin_id | X0_pin_id);

	//Init output port B15:8
	gpio_set_mode(X7_port, GPIO_MODE_OUTPUT_50_MHZ, GPIO_CNF_OUTPUT_OPENDRAIN, 
	X7_pin_id | X6_pin_id | X5_pin_id | X4_pin_id | X3_pin_id | X2_pin_id | X1_pin_id | X0_pin_id);

	//Init startup state of BSSR image to each Y scan
	for(uint8_t i = 0; i < 16; i++)
		x_bits[ i ] = X7_SET_OR | X6_SET_OR | X5_SET_OR | X4_SET_OR | X3_SET_OR | X2_SET_OR | X1_SET_OR | X0_SET_OR;
	
	// Initialize receive ringbuffer
	msx_dispatch_kq_put=0;
	msx_dispatch_kq_get=0;
	for(uint8_t i=0; i<MSX_DISP_QUEUE_SIZE; ++i)
	{
		msx_dispatch_keys_queue[i]=0;
	}
	
	// GPIO pins for MSX keyboard Y scan (PC3:0 of the MSX 8255 - PC3 MSX 8255 Pin 17)
	gpio_set_mode(Y3_port, GPIO_MODE_INPUT, GPIO_CNF_INPUT_PULL_UPDOWN, Y3_pin_id); // PC3 (MSX 8255 Pin 17)
	gpio_set(Y3_port, Y3_pin_id); //pull up resistor
	exti_select_source(Y3_exti, Y3_port);
	exti_set_trigger(Y3_exti, EXTI_TRIGGER_BOTH); //Int on both raise and fall transitions
	exti_reset_request(Y3_exti);
	exti_enable_request(Y3_exti);
	gpio_port_config_lock(Y3_port, Y3_pin_id);

	// GPIO pins for MSX keyboard Y scan (PC3:0 of the MSX 8255 - PC2 MSX 8255 Pin 16)
	gpio_set_mode(Y2_port, GPIO_MODE_INPUT, GPIO_CNF_INPUT_PULL_UPDOWN, Y2_pin_id); // PC2 (MSX 8255 Pin 16)
	gpio_set(Y2_port, Y2_pin_id); //pull up resistor
	exti_select_source(Y2_exti, Y2_port);
	exti_set_trigger(Y2_exti, EXTI_TRIGGER_BOTH); //Int on both raise and fall transitions
	exti_reset_request(Y2_exti);
	exti_enable_request(Y2_exti);
	gpio_port_config_lock(Y2_port, Y2_pin_id);

	// GPIO pins for MSX keyboard Y scan (PC3:0 of the MSX 8255 - PC1 MSX 8255 Pin 15)
	gpio_set_mode(Y1_port, GPIO_MODE_INPUT, GPIO_CNF_INPUT_PULL_UPDOWN, Y1_pin_id); // PC1 (MSX 8255 Pin 15)
	gpio_set(Y1_port, Y1_pin_id); //pull up resistor
	exti_select_source(Y1_exti, Y1_port);
	exti_set_trigger(Y1_exti, EXTI_TRIGGER_BOTH); //Int on both raise and fall transitions
	exti_reset_request(Y1_exti);
	exti_enable_request(Y1_exti);
	gpio_port_config_lock(Y1_port, Y1_pin_id);
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

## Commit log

2021-11-18 Delete PS2toMSX-BR Mapping210715.xlsm
    Replaced to an updated file
    [PS2toMSX-BR Mapping210715.xlsm]
2021-11-18 Updated port definitions
    Updated port definitions, reflecting Kicad schematics and PCB.
2021-11-18 Kicad files - Schematics and PCB
    [Cable.sch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]
2021-12-08 Database file and its source code
    This unit has a highly configurable capability, as it has an user updateable database, without need to recompile and upload a new code, to translate from PC keyboard to MSX. This excel file is the as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
